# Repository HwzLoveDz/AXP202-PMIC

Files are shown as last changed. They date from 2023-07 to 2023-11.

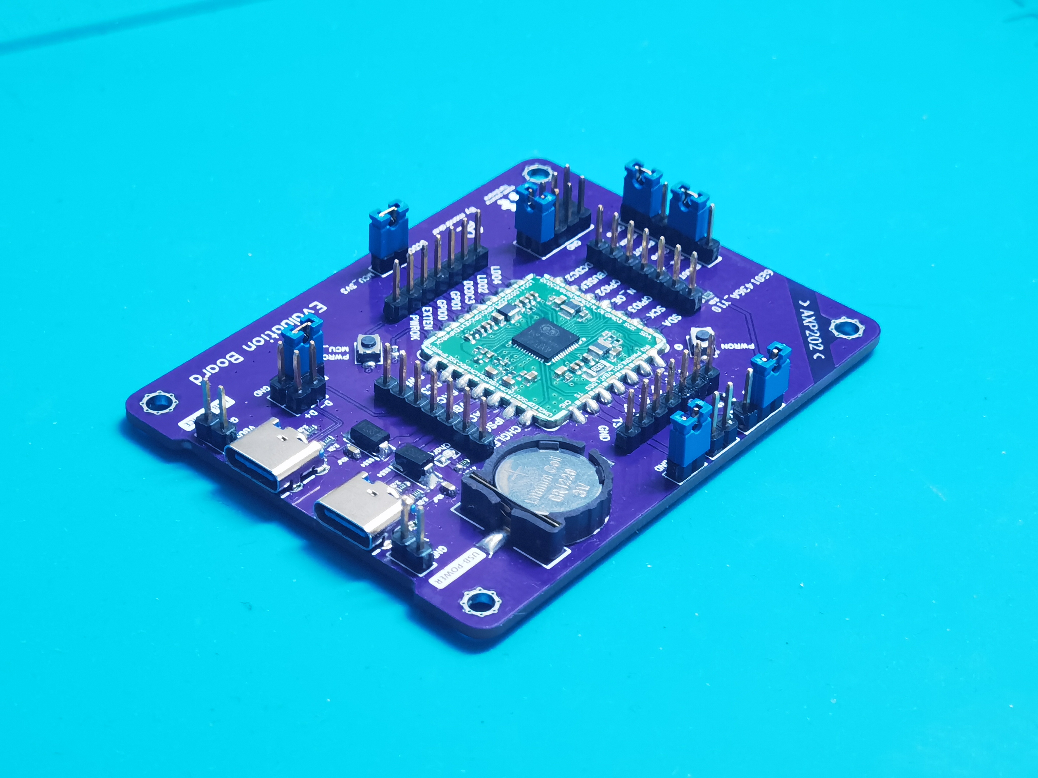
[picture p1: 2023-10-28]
hardware/底板图片.jpg

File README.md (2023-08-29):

# AXP202-PMIC
AXP202 Power management IC（AXP202电源管理芯片）

 
  
| 文件名称(file name) | 描述(description) |
|---|:---:|
| README_CN.md | [中文文档(Chinese Document)](https://github.com/HwzLoveDz/AXP202-PMIC/blob/main/README_CN.md) |
| README.md | [英文文档(English Document)](https://github.com/HwzLoveDz/AXP202-PMIC/blob/main/README.md) |

**Note:** The document is machine translated and does not guarantee that all sentences will be smooth or error-free

***

The hardware part is open source in the Lichuang open source platform, link address: https://oshwhub.com/mondraker
Sometimes if it is not reviewed on Saturdays and Sundays, the project will disappear and you can see the backup on Github and Gitee

##### If there is a problem, directly into the Q group to bombard me: 735791683🧨
* Why not use the latest version of AXP2101? First of all, the AXP2101 has too many functions, and the current DIY small devices simply cannot use so much. Secondly, because the price of the main product is relatively expensive, it is 10 times that of AXP202 (but if you have friends who need to do it later, you can also make one)
* The project has been verified for a long time, providing packaging, 3D files, etc., **sufficient information (including ESP-IDF routines and Arduino routines, Chinese and English manuals)**, and this stamp hole is also **no extra charge** at no extra charge, do not choose the half-hole process to grind 🤣 it yourself
* One chip 1.8 yuan, the rest are resistance, capacitance and inductance, a piece of "own whole" **within three dollars**
* Related materials, [BOM form](https://easyeda.online/ibom/d5313712.html), and component-related links are attached at the end of the article
* After a while, I will come out with a whole batch of modules of gold immersion + half-hole process, and put them in the TB shop together with snowflake lights: [Ultraman's electronic planet](https://m.tb.cn/h.50LlvTB )
* This module **P2P is compatible with AXP209** power management chip, and the program is also compatible, but AXP209 has one more OTP decoder than AXP202, and the register can be operated in the code

* * *

# Preface (Small Talk)
* Hello, everyone hasn't seen you for a long time, I haven't sent anything new for most of the year, and my friends think I'm retiring. In fact, I have been practicing in retreat during this time, busy with graduation projects, and learning ESP-IDF and LVGL by the way.
* The article may be relatively long, but this module is really easy to use, the information is very complete, I really hope that every interested friend can master him.
* Of course, I will share my gains during this period with you after sorting out the information later. Since the development board to be open source in two days also uses this power module, this module is first open sourced. (as shown below)

###### [Open source video trailer, click me directly](https://b23.tv/cWTMeIv)

**Development Board**
* 

**Module**
* 

**Test Baseplate**
* 

**Commented schematics**
* 
# Body (AXP202 Power Management Chip)
## Notes
### Since the chip has so many functions, I will divide it into the following parts for a general introduction
1. **Function part**: This part mainly introduces the design purpose, design ideas, chip functions, chip parameters and application scenarios

2. **Hardware part**: This part mainly introduces the chip peripheral circuit (detailing the functions and selection of each special device), module peripheral circuit (this part involves the default power supply voltage setting and boot mode setting), power module test backboard explanation, PCB parameters and precautions (thickness, etc.), power module wiring in the circuit (due to the particularity of the power module, it is easy to be unable to communicate)

3. **Software Part**: This part mainly introduces the functions implemented by the software, the use of routines, precautions, etc

4. **Video and related links section**: This part mainly includes the address of AXP173 project, the Github address of AXP202 project, the use of online bom and welding point tools (a very powerful thing developed by friends) and the video display and explanation of AXP202 module (strong response to launch a hand, now temporarily pigeon)

## Features section
### Design purpose
**1. When designing hardware, the power supply part has always been the beginning and top priority. I find that the core issues that are often discussed in everyone's daily production are:**
* How to design the power supply
* Find a small LDO
* Find an efficient DCDC
* Ask for a battery charging chip
* Where to find cheap power chips

**2. There are also many problems that players often encounter :**
* How to achieve efficient and reliable power path management of external input power supply and battery
* How to achieve long press to turn on and off
* How to accurately detect the battery level
* How to get the real-time status of the power supply
* What to do with low power consumption, what to do, what to do

**Well, I'll tell you now that there is a chip that can implement all the above functions, and is small in size, high efficiency, low in power consumption, and attractive in price???**



### Chip function
**1. on the function. (Official documentation is below)**
* 

**2. on the overview. (Official documentation is below)**
* 

### Chip parameters
**Here are mainly examples of power output capability parameters, other power parameters go to the data sheet. (Official documentation is below)**
* 

**If you also need 5V output, then the use of module IPSOUT pin + DCDC5V buck circuit can be easily achieved, the output capability depends on the input capability of the external power supply, and the chip has an EXTEN pin to control the EN pin of the external DCDC chip, saving the functional pin of the NCU, too fragrant. (Official documentation is below)**
* 

### Design ideas
**It is convenient to use the stamp hole module type directly, because the resistance and capacitance parameters on the periphery of this chip are relatively strange.**
* In order to facilitate the design and soldering of PCB circuit boards and increase the success rate, this design adopts modular thinking, the AXP202 peripheral circuit is packaged as a stamp hole module soldered to the motherboard, and all the user-defined pins are led out, so that it is convenient to use the resistance of the corresponding resistance value on the motherboard to configure these pins.

* In order to unify the package, the design uses a standard 2.54mm pitch LCC stamp hole for easy soldering, and a 4-layer PCB design is used to reduce the package size and bring out all the necessary functions.
### Application scenario
**All devices containing a microcontroller. (Official documentation is below)**
* 

## Hardware section
### Chip peripheral circuitry
**The schematic is written in detail, here is a brief summary**

* First of all, the power input part, **as shown in the upper left area of the figure**. VBAT is the positive terminal of the battery, and a 0603 package is connected in parallel with a 10uF withstand 16V capacitor for filtering. ACIN is an external DC power supply pin, which can accommodate 5V/2A power supply entry, VBUS is an external USB power input, which can accommodate 5V/1A power supply entry, so a 0603 package 4.7uF capacitor is connected in parallel for power supply filtering, and two 2.2ohm resistors are deliberately connected in series to prevent oscillation, reduce the capacitor charging speed, and better absorb the noise of the power supply. This section can also be paralleled with Zener diodes at the power supply to reduce the risk of high-voltage breakdown, which is not added due to the size limitation of the module and the fact that it is not functionally sensitive. BACKUP is the positive terminal of the external backup battery, connected to a conventional RTC/BIOS battery.

* This is followed by the DCDC buck section, **as shown in the upper right area of the figure**. This part of the circuit is an independent area that requires external access to the system input power supply IPSOUT, which can reduce the internal voltage IPSOUT to the power chip voltage regulation range, if the application does not need to use a DC-DC only need to suspend the corresponding LX pin. 4.7uH inductance is recommended when the output voltage is below 2.5V, 2.2uH inductance is recommended when the output voltage is above 2.5V, and the inductor saturation current needs to be greater than 50% of the maximum required current, here because 4.7uH has 0806 package, so all 4.7uH is used, also to reduce the volume. R17 must be 30mΩ/1%/1206 resistance, PCB layout attention chip 42/43 pin must be connected to R17 resistance PAD to ensure that the signal is detected directly from the resistor PAD, because R17 for the battery charging current, discharge current and charging voltage of the detection resistance, not only high accuracy but also need to strictly consider interference in the layout.

* This is followed by the exit of the signal and function pins, as well as the circuit section outside the internal reference voltage of the chip, **as shown in the lower left area of the figure**. The following two GPIOs have additional functions in addition to the normal input and output capability: GPIO0: ADC/LDO5 (output drive capability of 50mA), GPIO1: ADC. PWRON is the power chip boot pin, active low, R24 pull-up to LDO1 to prevent false triggering. N_OE can be used to power on the device directly via an external power supply. N_VBUSEN to choose whether VBUS power is enabled. IRQ interrupt signal pin with optional pull-up to LDO1 or MCU_3V3. I2C uses a 2.2k resistor to pull up to MCU_3V3.

* Finally, there is the LDO (Low Dropout Linear Regulator) output section, **see the lower right area of the figure**. This part is also a separate area in the functional block diagram, which requires an external access system to supply ISPOUT. PWROK is the MCU enable pin, and the RESET button is connected to the EN pin of the MCU to restart the MCU and pull up to the MCU power supply pin. DC3SET sets the pin for DCDC3 voltage, 3.3V/2.5V for APS or LDO1, 1.8V for ground, and 1.2V/1.5V for floating.

* 

### Module peripheral circuit
**The picture below is very detailed, not to be repeated**

* 

### Power module test backplane explanation
**As shown in the figure above, all functions are introduced, some pins that can be set externally on the chip can be set using a jump cap, and a 5V DCDC boost is added for basic testing, and the ground wire leads less and can be added at your discretion. Or draw a test board according to the main control chip to be used, my test base board is only used to screen which chip is suitable and basic functional testing, because I directly drew the ESP32 test board, so I did not continue to optimize this base board (there may be a breadboard module later).**

### Wiring of the power module in the circuit
**Compared with ordinary I2C modules, the power management module also provides power to the main control chip, in addition, AXP202 must be in the boot state, must be common, otherwise the two can not communicate normally.**
* 

### PCB parameters and stamp hole handling considerations
**Place a single 1mm (the picture below is 1.6mm very thick, just for demonstration purposes), four layers. There is no need for the half-hole process, after coming back, it is crimped, and you need to use tweezers to cut out the excess copper in the half-hole, and then grind it off with sandpaper of about 800 mesh. (The following is a simple step-by-step demonstration)**

* Before processing (silver for OK, yellow for OK)
* 
* Processing (tweezers pick out)
* 
* Processing (after picking out)
* 
* 
* In process (sanding)
* There is no picture, don't try too hard, grind and take a look, don't grind the copper on the edge of the board.
* After treatment (you can use higher mesh sandpaper to polish it finely)
* 

### PS
**The hole on the top of the module is for easy disassembly and assembly**
* 

## Software section
### **[GitHub link](https://github.com/HwzLoveDz/AXP202-PMIC)**
### **[Gitee link](https://gitee.com/mondraker/AXP202-PMIC)**
### Statement:
* axp20x libraries and Arduino-related routines are all from Lewis He, thanks to the open source (open source license: MIT)
* Original GitHub link: github:https://github.com/lewisxhe/AXP202X_Libraries
* Subsequent routines will be written around this library, adding other commonly used registers and functions, such as LED indicator charging control, etc., and future changes will be updated to GitHub/Gitee

### Description:
* The library is also compatible with AXP173/192/202, etc
* Basically realize all the functions of the chip
* There are relevant function comments in the code, which can be studied and written with the official register document
* The code is written using an independent I2C interface, and only need to write an interface library to port to other platforms, which is very convenient
* **If you have doubts in the code, you can refer to this open source [AXP173](https://oshwhub.com/mondraker/axp173) to learn, or bombard me in the crowd**

## Video and related links section
* **[GitHub profile](https://github.com/HwzLoveDz)**
* **[Gitee profile](https://gitee.com/mondraker)**
* **[bilibili homepage](https://space.bilibili.com/240319986)** **(here is the AXP202 (QFN) chip soldering tutorial)**
* **[Online BOM address](https://easyeda.online/ibom/d5313712.html)** **(developed by a friend, like ibom, but online, and mobile phone can also be browsed, a later issue will focus on him)**
* **QQ Group Number: 735791683**
* **Device purchase link in accessory BOM**

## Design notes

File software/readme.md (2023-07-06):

以下代码中AXP20X的所有库均来自Lewis He大佬，该库同时兼容AXP173/192/202等，原GitHub链接：
github:https://github.com/lewisxhe/AXP202X_Libraries

Arduino文件夹下AXP202X为标准arduino库，可以移到libraries文件夹下直接使用；
ESP-IDF文件夹为ESP-IDF例程，我使用idf5.0版本编译成功；

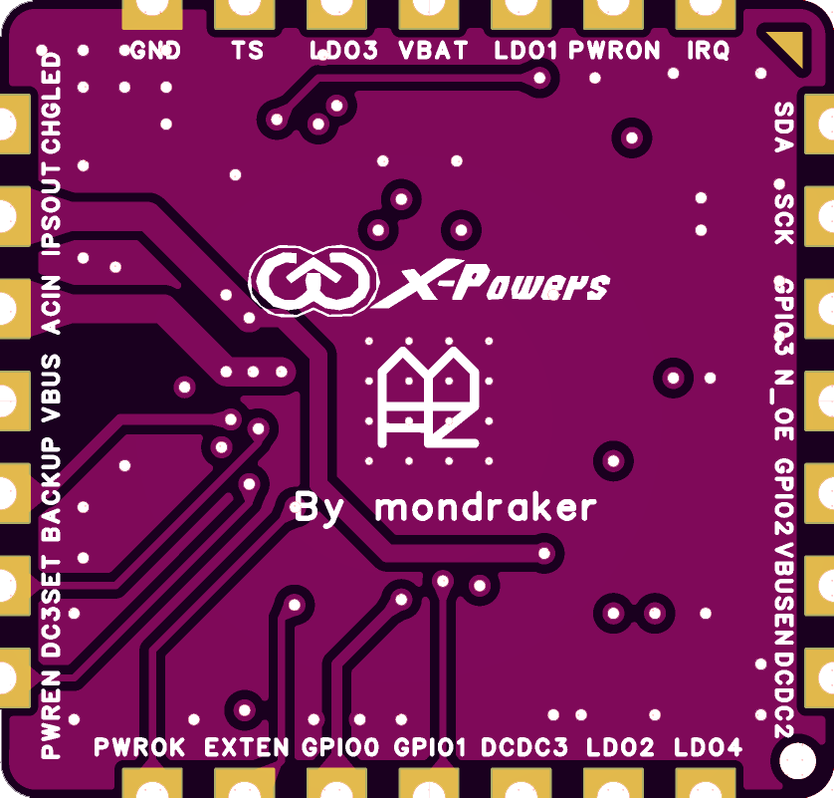
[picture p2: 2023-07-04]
hardware/AXP202模块渲染/F1.png

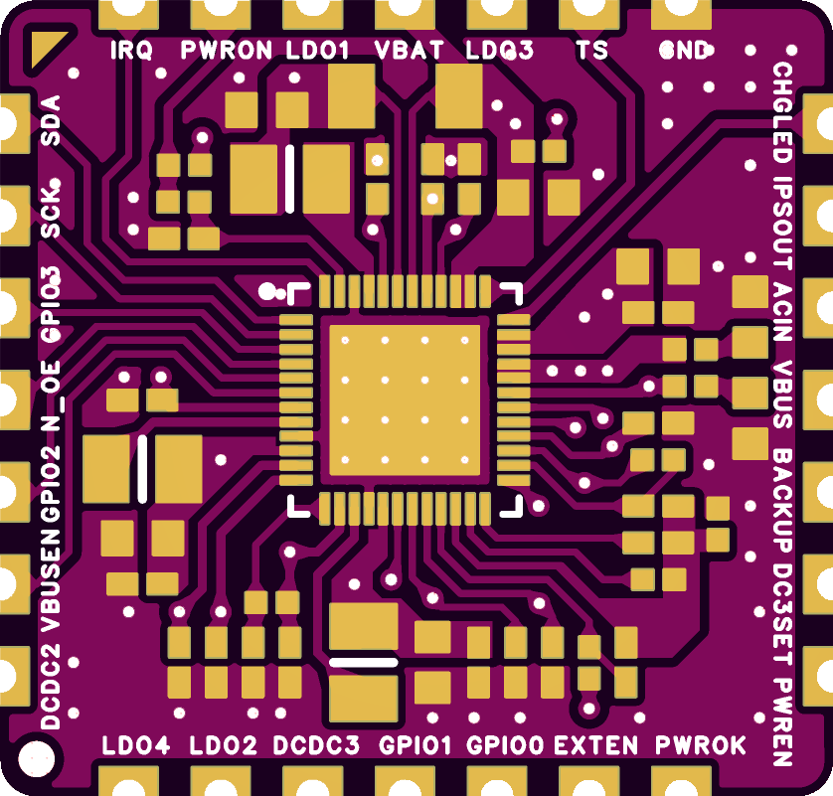
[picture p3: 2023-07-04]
hardware/AXP202模块渲染/z11.png

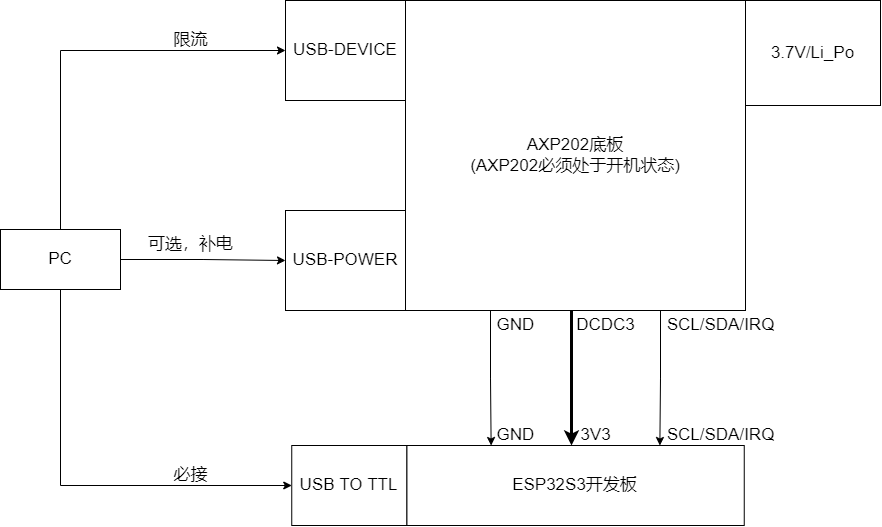
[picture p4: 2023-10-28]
hardware/底板与开发板接线框图.drawio.png

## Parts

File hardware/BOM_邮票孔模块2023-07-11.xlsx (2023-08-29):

在线BOM与焊接点位地址（手机也可查看）：https://easyeda.online/ibom/d5313712.html
ID | Name | Designator | Footprint | Quantity | Manufacturer Part | 立创料号 | 备注
1 | AXP202 | U1 | QFN48 | 1 | 【淘宝】https://m.tb.cn/h.5agVBVR?tk=pbYndH4zCvU CZ0001 「全新原装正品 AXP202 贴片QFN 电源管理芯片」 点击链接直接打开 或者 淘宝搜索直接打开 |  | 链接挂了就直接TB搜索AXP202，其中我只测试过鹏盛微、义胜、品信达三家，其中义胜、品信达两家芯片丝印一致。三家都可以用，都没有什么问题，鹏盛微家的没有打磨痕迹。
电容
2 | 10uF/0603 | C1,C11,C12,C14,C18 | C0603 | 5 | 随便品牌都行，耐压6.3V以上
3 | 1nF | C2,C17 | C0402 | 2
4 | 2.2uF | C3 | C0402 | 1
5 | 10uF | C4,C9,C19 | C0402 | 3
6 | 1uF | C5,C7,C20,C23,C10 | C0402 | 5
7 | 4.7uF | C6,C8,C24,C25,C26 | C0402 | 5
8
9 | 220nF | C13,C22 | C0402 | 2
10 | 4.7uF/0603 | C15,C16 | C0603 | 2
11 | 100pF | C21 | C0402 | 1
电阻
12 | 10k | R2 | R0402 | 1 | 随便品牌都行，但是 精度必须至少±１%
13 | 2.2R | R4,R6 | R0402 | 2
14 | 1R | R5 | R0402 | 1
15 | 200k/1% | R8 | R0402 | 1
16 | 1k | R10 | R0402 | 1
17 | 0R | R11,R12 | R0402 | 2
18 | 4.7k | R24 | R0402 | 1
19 | 0.03Ω | R17 | R1206 | 1 | RTT06R030FTP | C104923 | 只要精度高，什么牌子无所谓，我用的这个
电感
20 | 4.7uH | L1,L2,L3 | L0806 | 3 | MPL2016S4R7MHT | C98335 | 追求功耗推荐用这个，额定1.1A，但内阻110mΩ
 |  | L1,L2,L3 | L1008 | 3 | FHD252012S-4R7MT | C602016 | 追求性能推荐用这个，额定1.6A，但内阻260mΩ
电感替代型号

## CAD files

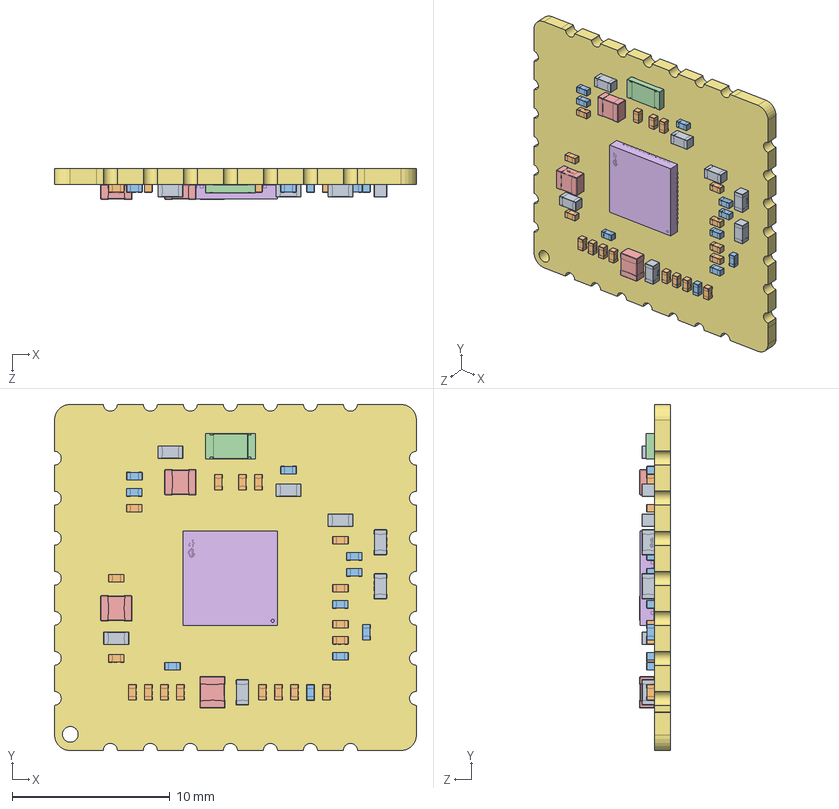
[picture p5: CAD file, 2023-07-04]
hardware/AXP202模块渲染/3D_邮票孔模块_2023-03-31.step.SLDASM
23.0 x 22.0 x 1.95 mm
SOLID.step x 7
SOLID-0.step x 18
SOLID-1.step x 10
COMPOUND.step
SOLID-2.step x 3
COMPOUND-3.step
COMPOUND-4.step

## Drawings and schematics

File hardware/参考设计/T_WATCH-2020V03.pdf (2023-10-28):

USB | UART

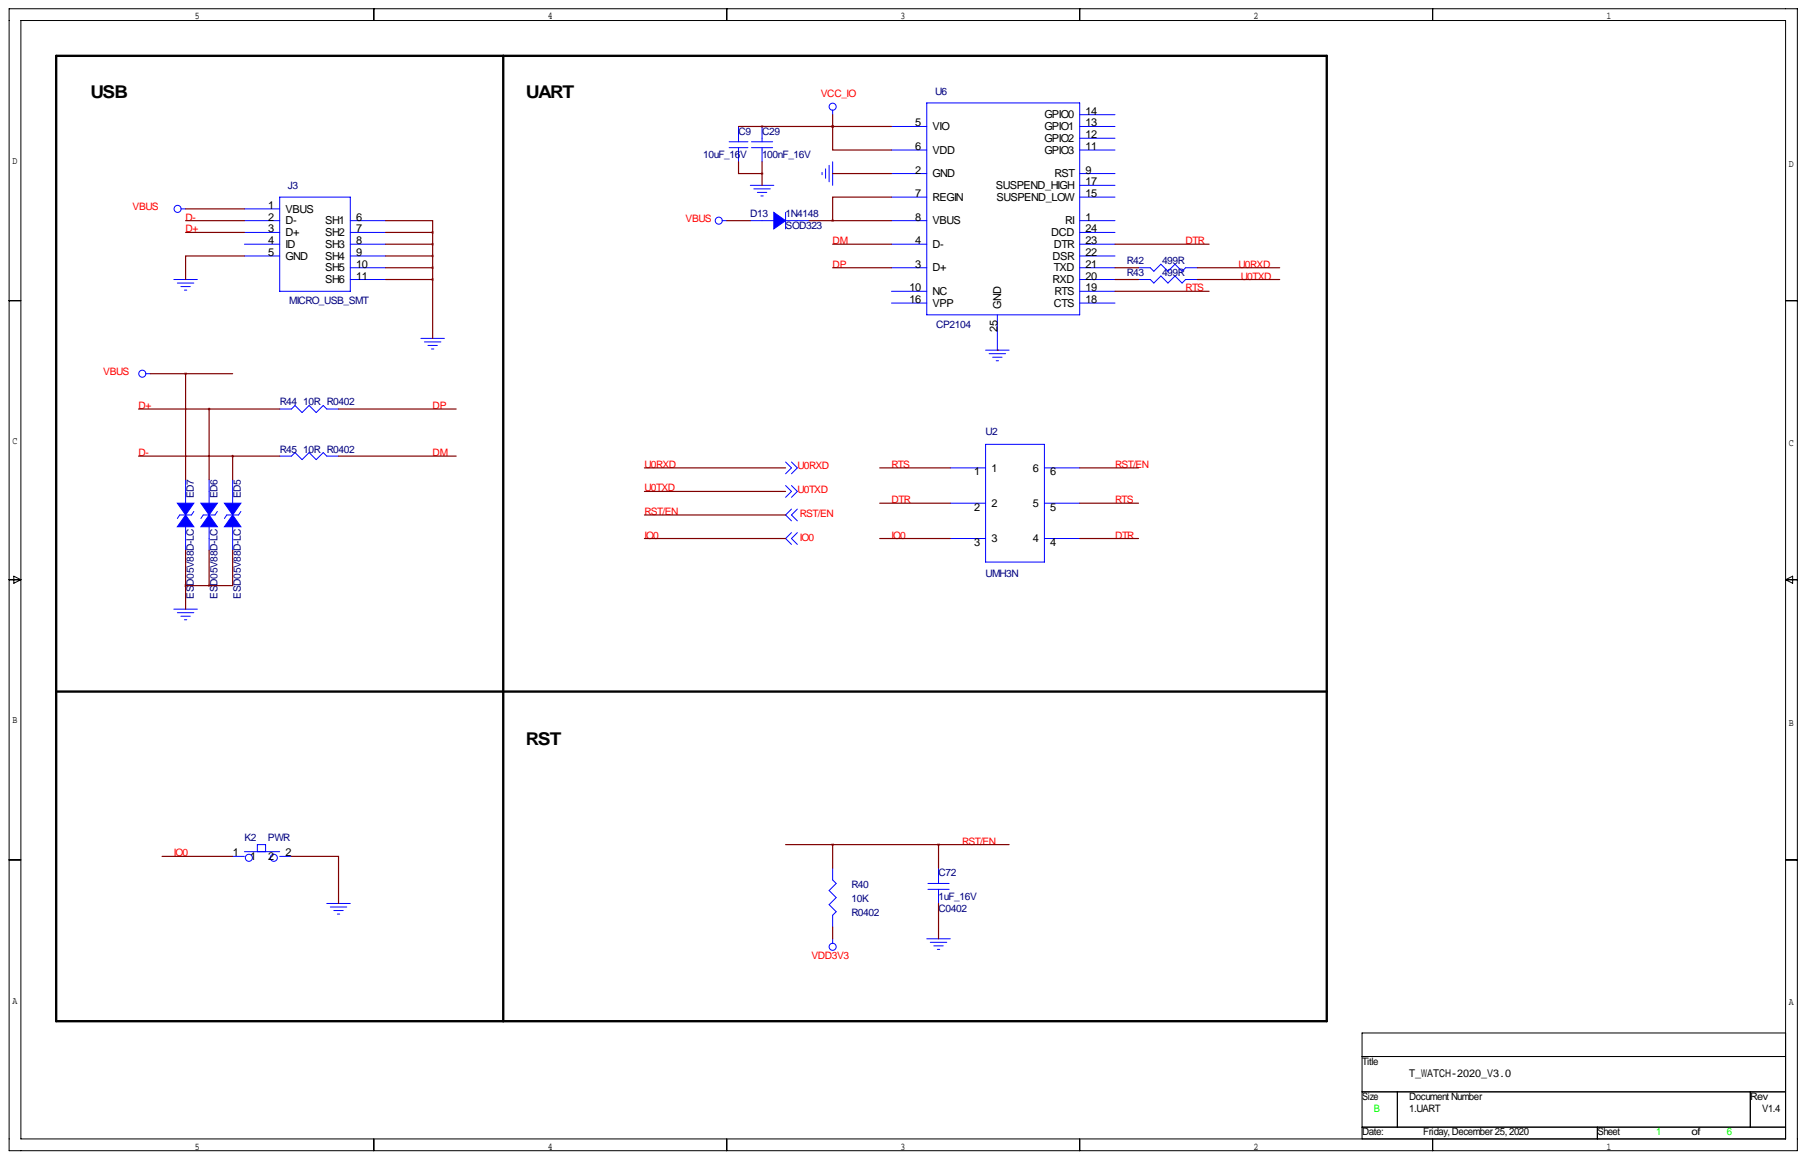
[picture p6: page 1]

Size B | Document Number 1.UART | Rev V1.4

Date: Friday, December 25, 2020 | Sheet of

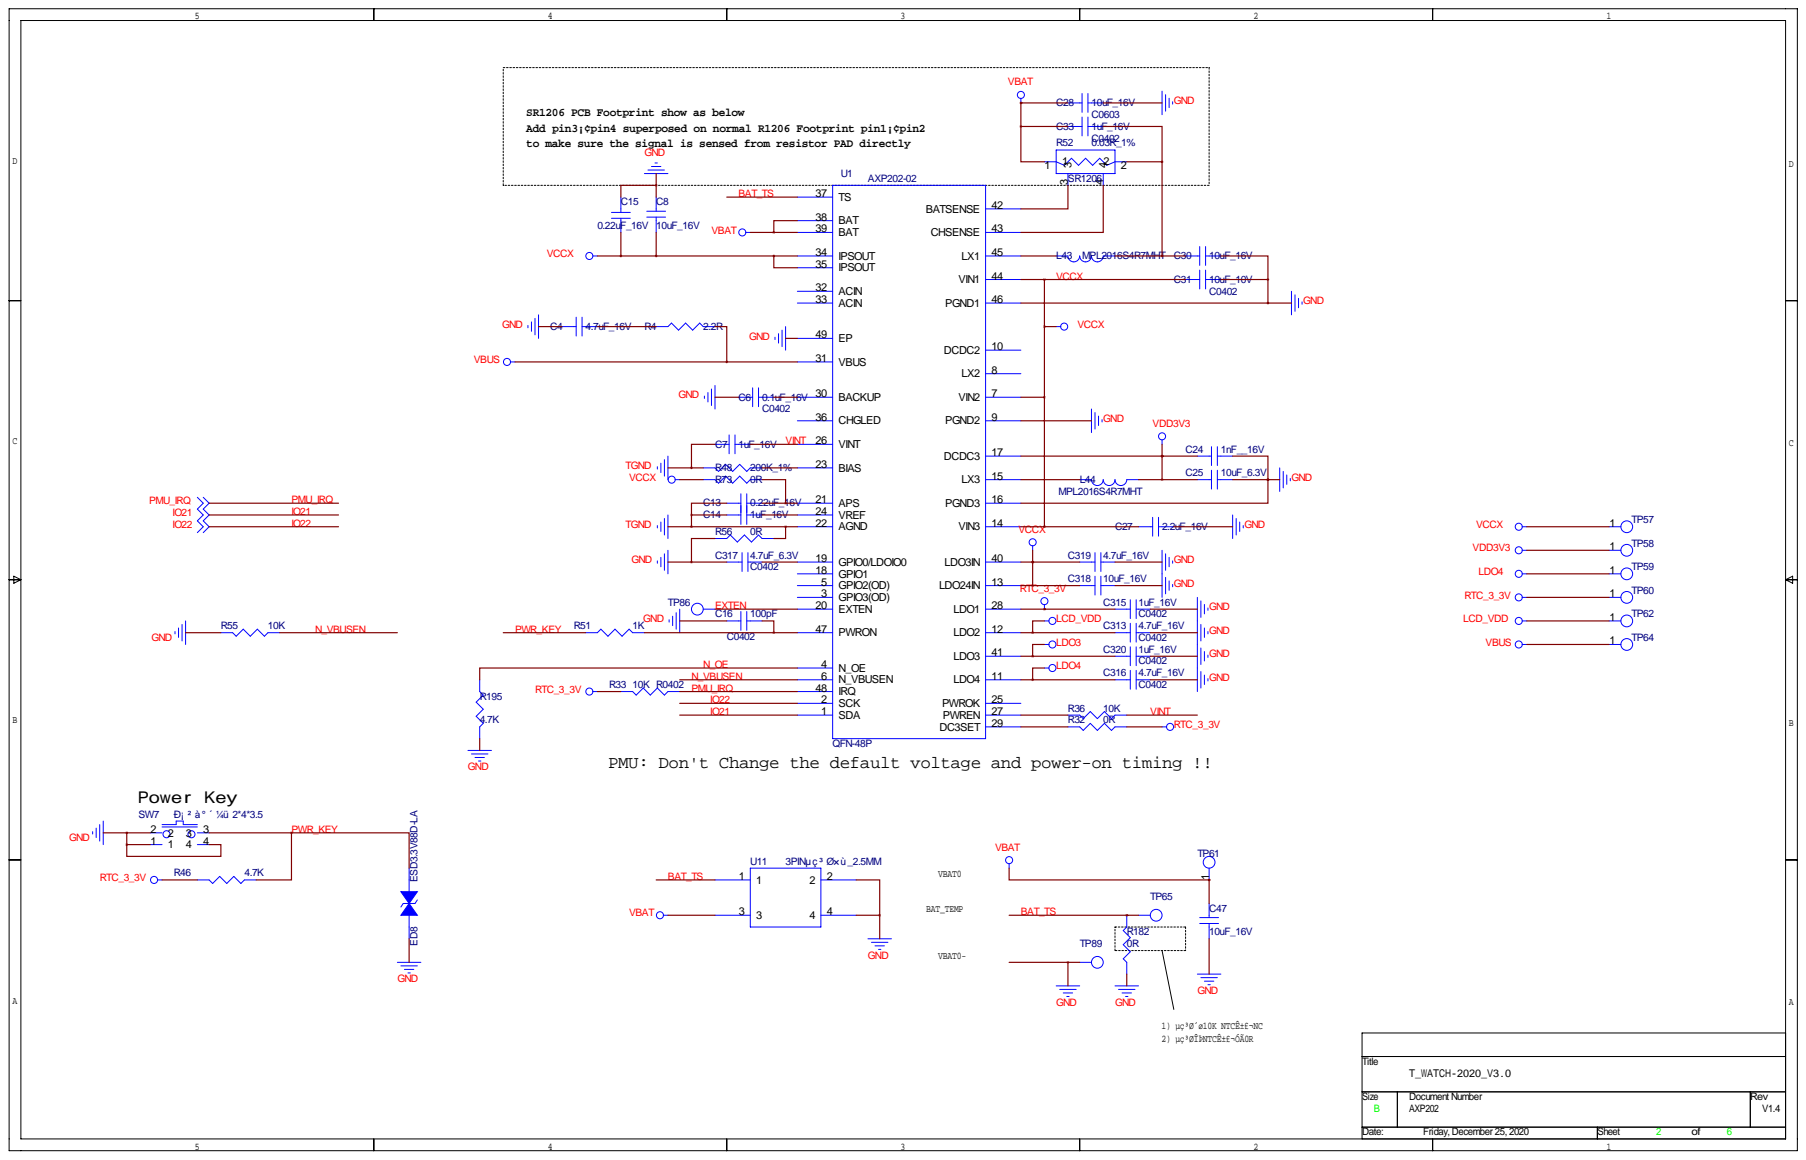
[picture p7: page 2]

SR1206 PCB Footprint show as below

Add pin3¡¢pin4 superposed on normal R1206 Footprint pin1¡¢pin2

to make sure the signal is sensed from resistor PAD directly

15 LX3 | MPL2016S4R7MHT

C14 | 1uF_16V | 14 VIN3

40 LDO3IN

PMU: Don't Change the default voltage and power-on timing !!

## ESP32 Module:with 1.8V Flash & SRAM

The operating voltage for signals marked in blue is 1.8V.

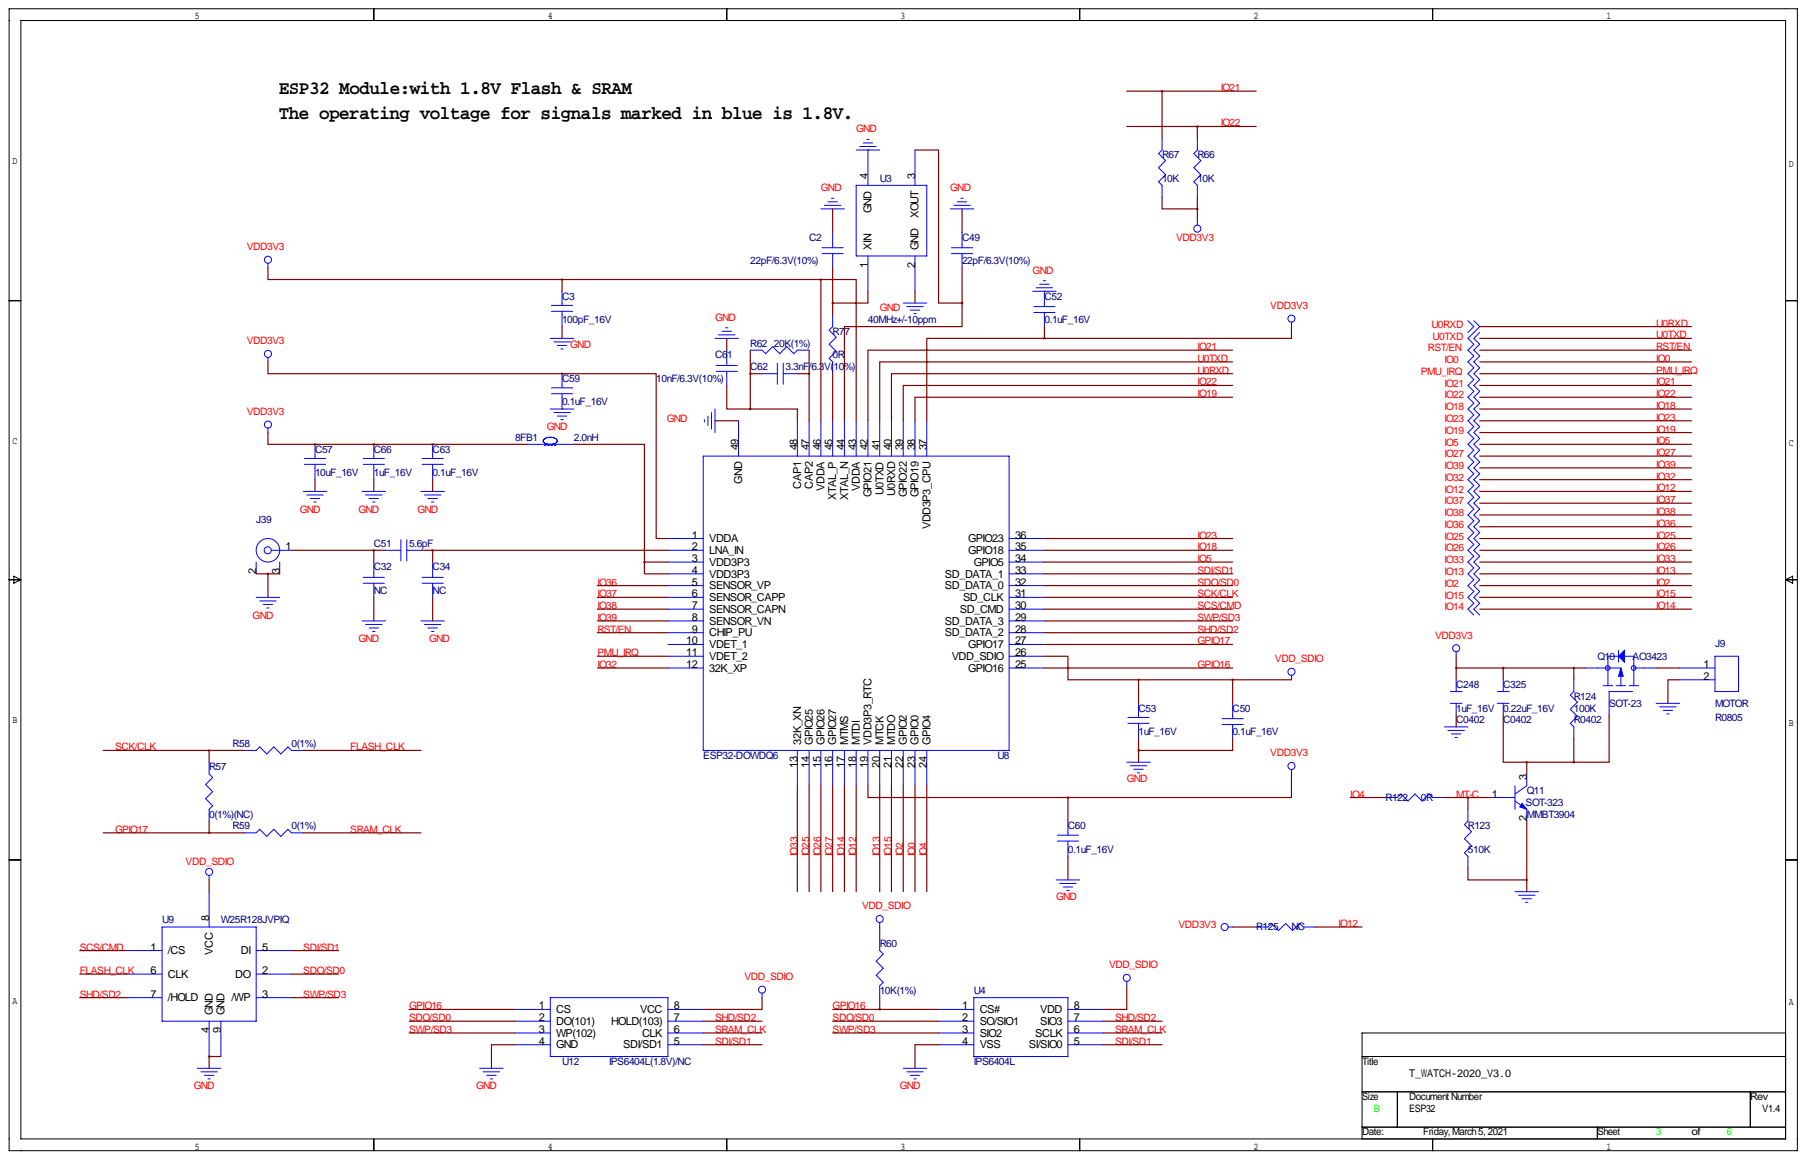
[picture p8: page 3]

Size B | Document Number ESP32 | Rev V1.4

Friday, March 5, 2021

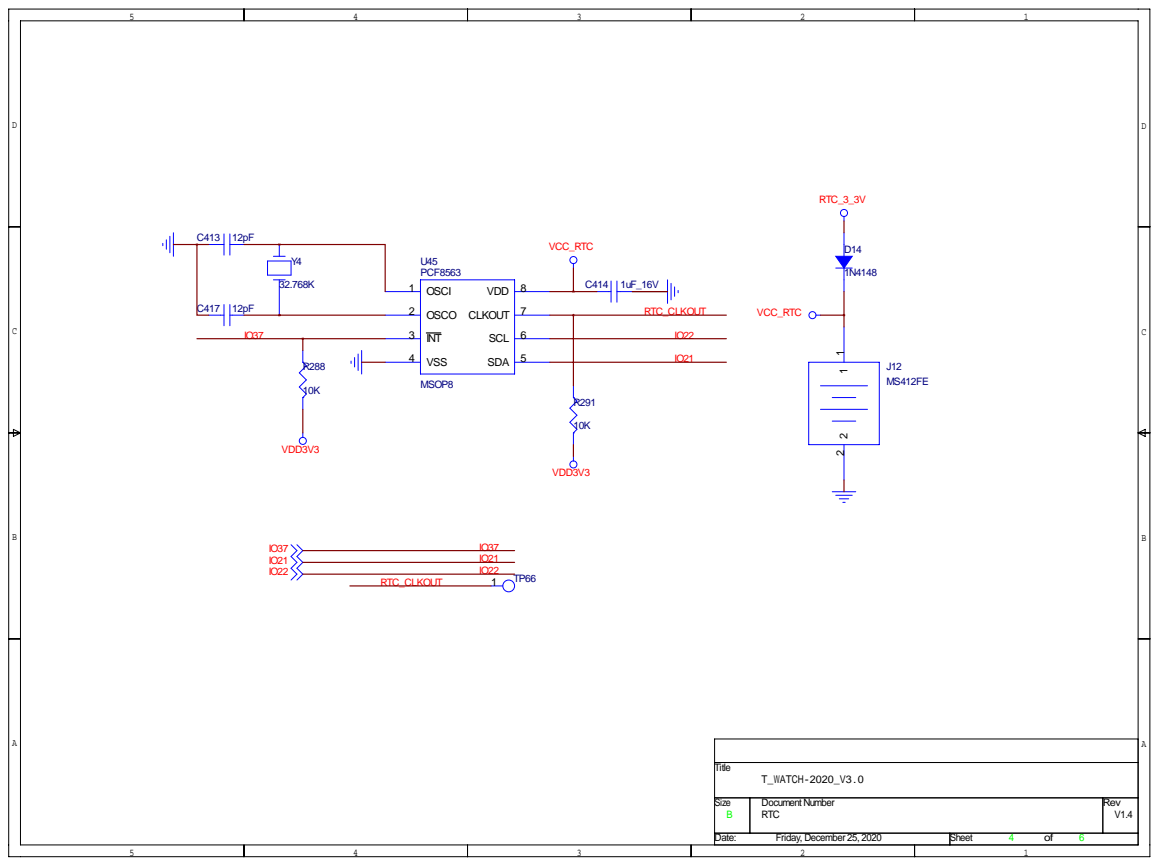
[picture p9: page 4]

# LCD_1.54-TOUCH

# IF=3*15MA

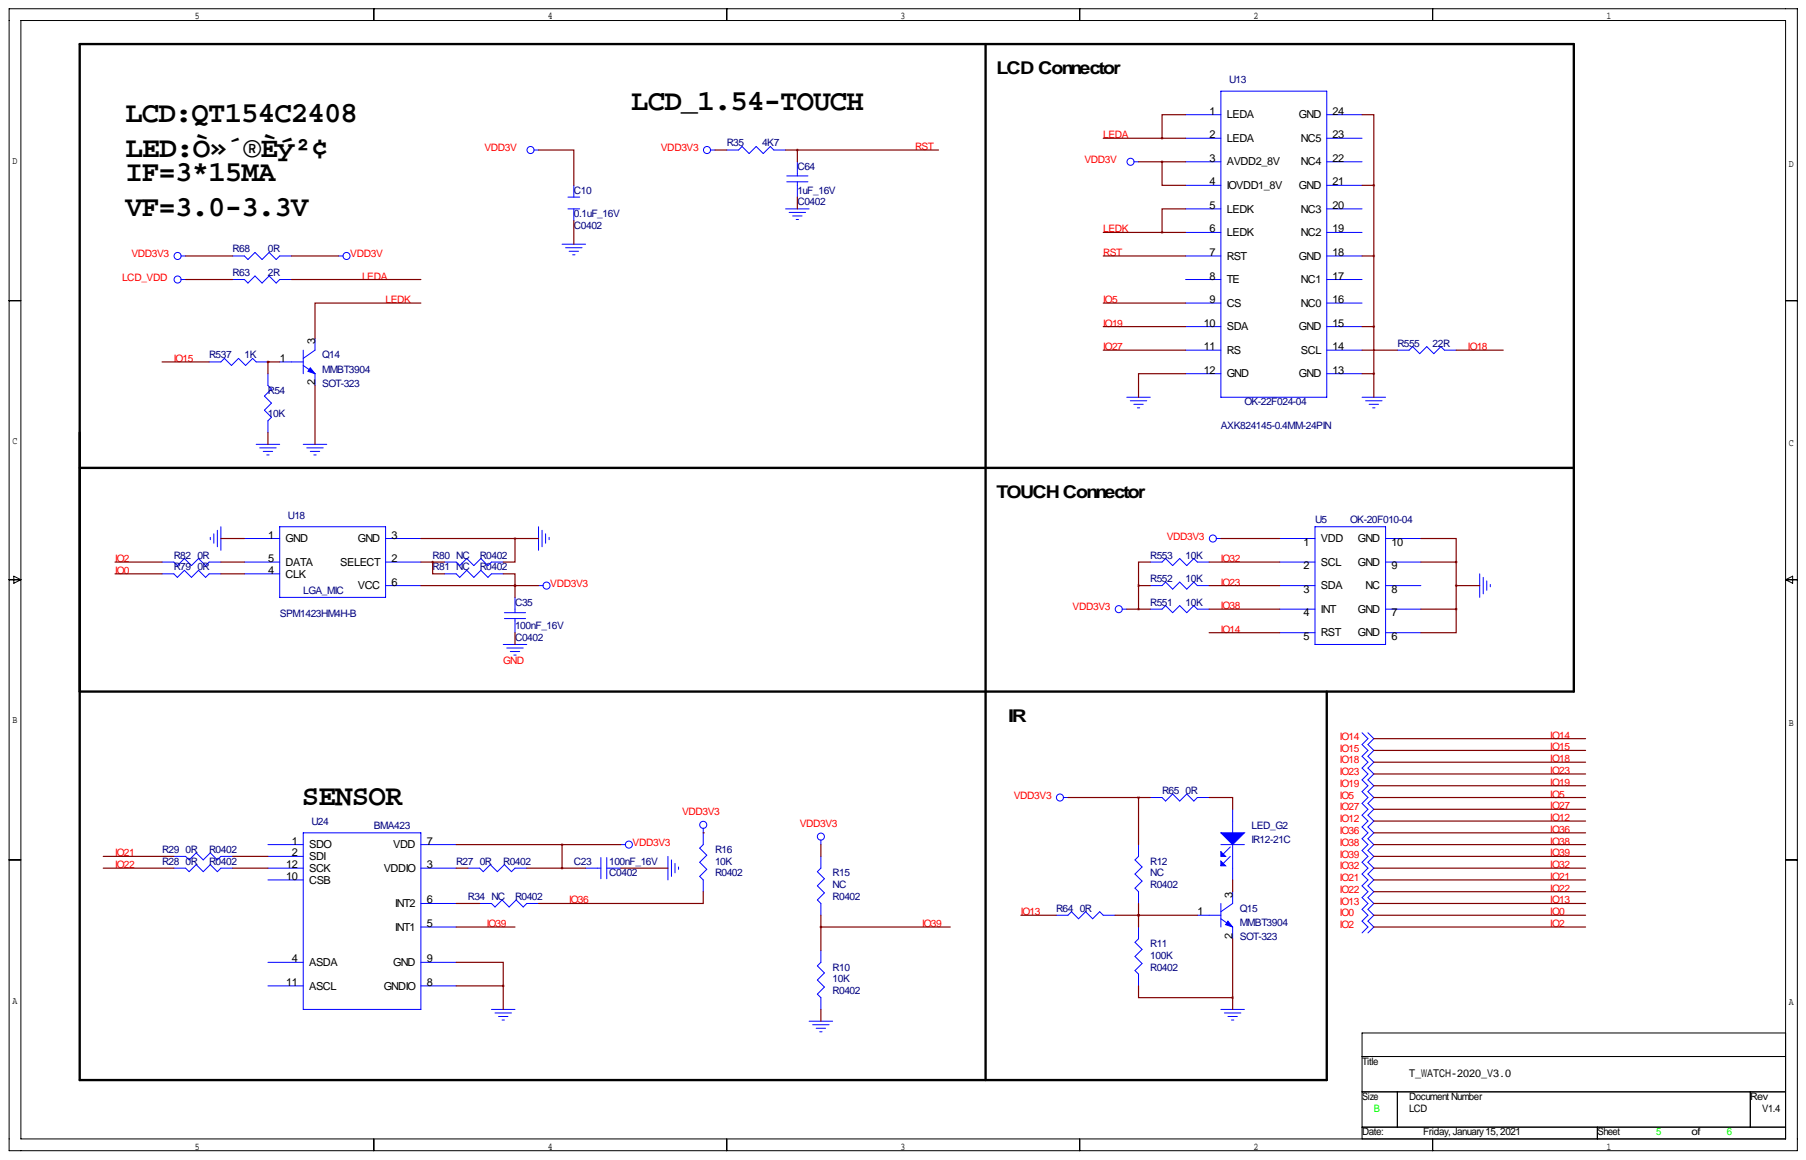
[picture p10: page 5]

Size B | Document Number LCD | Rev V1.4

Friday, January 15, 2021

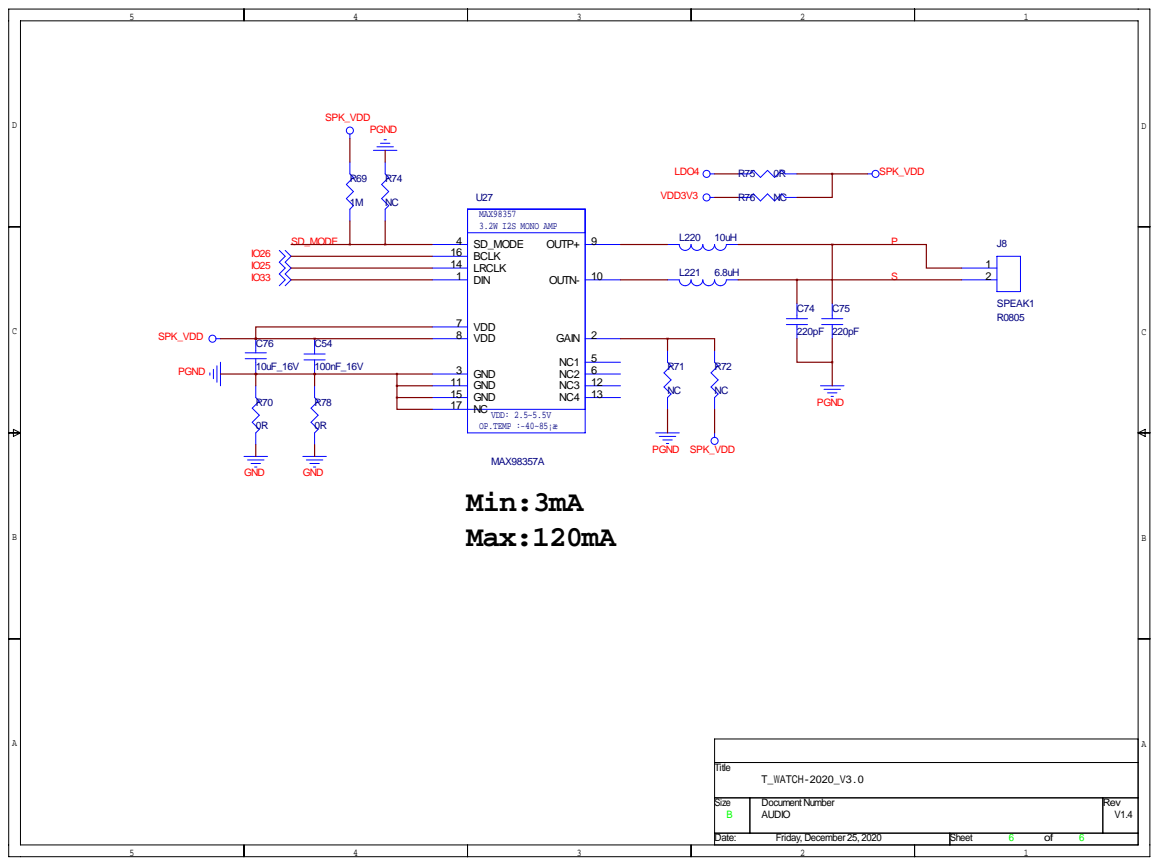
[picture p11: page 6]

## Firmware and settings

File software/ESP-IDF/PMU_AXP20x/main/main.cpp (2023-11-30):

/////////////////////////////////////////////////////////////////
/*
MIT License

Copyright (c) 2020 lewis he

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
main.cpp - AXP202X_Library idf Programming example
Created by Lewis he on July 29, 2020.
github:https://github.com/lewisxhe/ESP_IDF_AXP20x_Library
*/
/////////////////////////////////////////////////////////////////
//! 请注意外设最大支持电压，调压可能会损坏外设器件
//IIC部分官方文档：https://docs.espressif.com/projects/esp-idf/en/release-v4.4/esp32c3/api-reference/peripherals/i2c.html

extern "C" {

#include "i2c_port.h"

}

#include "axp20x.hpp"

static const char *TAG = "AXP20x";

// //! ESP32C3只有I2C_NUM_0一个I2C通道

static QueueHandle_t gpio_evt_queue = NULL;

static void IRAM_ATTR axp_isr_handler(void *arg)
{
    uint32_t gpio_num = (uint32_t) arg;
    xQueueSendFromISR(gpio_evt_queue, &gpio_num, NULL);
}

static void axp_irq_init()
{
    static gpio_config_t io_conf;
    //enable interrupt
    io_conf.intr_type = GPIO_INTR_NEGEDGE;
    //set as input mode
    io_conf.mode = GPIO_MODE_INPUT;
    //bit mask of the pins that you want to set
    io_conf.pin_bit_mask = GPIO_INPUT_PIN_SEL;
    //disable pull-down mode
    io_conf.pull_down_en = GPIO_PULLDOWN_DISABLE;
    //enable pull-up mode
    io_conf.pull_up_en = GPIO_PULLUP_ENABLE;
    //configure GPIO with the given settings
    gpio_config(&io_conf);
    //change gpio intrrupt type for one pin
    gpio_set_intr_type(AXP_ISR_GPIO, GPIO_INTR_NEGEDGE);
    //install gpio isr service
    gpio_install_isr_service(0);
    //hook isr handler for specific gpio pin
    gpio_isr_handler_add(AXP_ISR_GPIO, axp_isr_handler, (void *) AXP_ISR_GPIO);
    //create a queue to handle gpio event from isr
    gpio_evt_queue = xQueueCreate(10, sizeof(uint32_t));
}

static void axp_init()
{
    if (axp.begin(twi_read, twi_write, AXP202_SLAVE_ADDRESS))
    {
        ESP_LOGE(TAG, "Error init axp20x !!!");
        while (1);
    }
    ESP_LOGI(TAG, "Success init axp20x !!!");
}

static void axp_config()
{
    // 两个警告等级（类似于手机20%一提醒，10%一提醒）和一个关机电压（类似于手机3%关机，实际显示0%）
    axp.setVWarningLevel1(3450);
    axp.setVWarningLevel2(3400);
    axp.setPowerDownVoltage(2600);
    uint16_t level1 = axp.getVWarningLevel1();
    uint16_t level2 = axp.getVWarningLevel2();
    uint16_t level3 = axp.getPowerDownVoltage();
    ESP_LOGI(TAG, "getVWarningLevel1:%u mV", level1 );
    ESP_LOGI(TAG, "getVWarningLevel2:%u mV", level2);
    ESP_LOGI(TAG, "getPowerDonwLevel3:%u mV", level3);

    axp.setPowerOutPut(AXP202_DCDC3, AXP202_ON); // 主控供电，十轴传感器供电
    axp.setPowerOutPut(AXP202_DCDC2, AXP202_ON);

    axp.setLDO2Voltage(3300); // 屏幕与SD卡供电
    axp.setPowerOutPut(AXP202_LDO2, AXP202_ON);

    axp.setLDO4Voltage(AXP202_LDO4_3300MV); // 音频供电
    axp.setPowerOutPut(AXP202_LDO4, AXP202_ON);

    axp.setLDO3Voltage(3500); // 触觉驱动器供电
    axp.setPowerOutPut(AXP202_LDO3, AXP202_ON);

    axp.setPowerOutPut(AXP202_EXTEN, AXP202_ON);

    if (axp.isDCDC2Enable())
    {
        ESP_LOGI(TAG, "DC2: %u mV", axp.getDCDC2Voltage());
    }
    else
    {
        ESP_LOGI(TAG, "DC2: DISABLE");
    }

    if (axp.isDCDC3Enable())
    {
        ESP_LOGI(TAG, "DC3: %u mV", axp.getDCDC3Voltage());
    }
    else
    {
        ESP_LOGI(TAG, "DC3: DISABLE");
    }

    if (axp.isLDO2Enable())
    {
        ESP_LOGI(TAG, "LDO2: %u mV", axp.getLDO2Voltage());
    }
    else
    {
        ESP_LOGI(TAG, "LDO2: DISABLE");
    }

    if (axp.isLDO3Enable())
    {
        ESP_LOGI(TAG, "LDO3: %u mV", axp.getLDO3Voltage());
    }
    else
    {
        ESP_LOGI(TAG, "LDO3: DISABLE");
    }

    if (axp.isLDO4Enable())
    {
        ESP_LOGI(TAG, "LDO4: %u mV", axp.getLDO4Voltage());
    }
    else
    {
        ESP_LOGI(TAG, "LDO4: DISABLE");
    }

    if (axp.isExtenEnable())
    {
        ESP_LOGI(TAG, "Exten: ENABLE");
    }
    else
    {
        ESP_LOGI(TAG, "Exten: DISABLE");
    }

    // When the chip is axp192 / 173, the allowed values are 0 ~ 15,
    // corresponding to the axp1xx_charge_current_t enumeration
    //  axp.setChargeControlCur(AXP1XX_CHARGE_CUR_550MA);

    // axp202 allows maximum charging current of 1800mA, minimum 300mA
    axp.setChargeControlCur(300);

    axp.setChgLEDContrl(AXP20X_LED_CHARGING_CTL);   // CHGLED由充电状态控制
    axp.setChgLEDChargingMode(AXP20X_LED_LIGHT_WHEN_CHARGING);  // CHGLED由充电状态控制模式
    // axp.setChgLEDContrl(AXP20X_LED_REG_32H_CTL); // CHGLED由REG32H控制
    // axp.setChgLEDMode(AXP20X_LED_BLINK_4HZ);  // CHGLED由REG32H控制模式

    ESP_LOGI(TAG, "setChargeControlCur:%u", axp.getChargeControlCur());
    ESP_LOGI(TAG, "getCoreTemp:%.2f C", axp.getTemp());

    // Backup battery charge control
    // Backup Battery model: KTS CR2032W 3.0V 220mAh
    axp.setBackupChargeControl(AXP202_ON);
    axp.setBackupChargeVoltage(AXP202_BACKUP_VOLTAGE_3V0);
    axp.setBackupChargeCurrent(AXP202_BACKUP_CURRENT_100UA);

    axp.setGPIOMode(AXP_GPIO_0, AXP_IO_OUTPUT_HIGH_MODE); // 打开主板指示灯PIO0
    axp.gpioWrite(AXP_GPIO_0, 1);
}

static void axp_info()
{
    if (axp.isDCDC2Enable())
    {
        ESP_LOGI(TAG, "DC2: %u mV", axp.getDCDC2Voltage());
    }
    else
    {
        ESP_LOGI(TAG, "DC2: DISABLE");
    }

    if (axp.isDCDC3Enable())
    {
        ESP_LOGI(TAG, "DC3: %u mV", axp.getDCDC3Voltage());
    }
    else
    {
        ESP_LOGI(TAG, "DC3: DISABLE");
    }

    if (axp.isLDO2Enable())
    {
        ESP_LOGI(TAG, "LDO2: %u mV", axp.getLDO2Voltage());
    }
    else
    {
        ESP_LOGI(TAG, "LDO2: DISABLE");
    }

    if (axp.isLDO3Enable())
    {
        ESP_LOGI(TAG, "LDO3: %u mV", axp.getLDO3Voltage());
    }
    else
    {
        ESP_LOGI(TAG, "LDO3: DISABLE");
    }

    if (axp.isLDO4Enable())
    {
        ESP_LOGI(TAG, "LDO4: %u mV", axp.getLDO4Voltage());
    }
    else
    {
        ESP_LOGI(TAG, "LDO4: DISABLE");
    }

    if (axp.isExtenEnable())
    {
        ESP_LOGI(TAG, "Exten: ENABLE");
    }
    else
    {
        ESP_LOGI(TAG, "Exten: DISABLE");
    }
}

extern "C" void app_main(void)
{
    ESP_ERROR_CHECK(i2c_master_init());

    axp_init();

    axp_info();

    axp_irq_init();

    axp_config();

    // //! Enable all irq channel
    axp.enableIRQ(AXP202_ALL_IRQ, true);

    axp.clearIRQ();

    uint32_t io_num;
    for (;;) {

        if (xQueueReceive(gpio_evt_queue, &io_num, portMAX_DELAY)) {
            if (io_num == AXP_ISR_GPIO) {
                axp.readIRQ();
                if (axp.isPEKShortPressIRQ()) {
                    ESP_LOGI(TAG, "AXP202 PEK key Click");
                }
                axp.clearIRQ();
            }
        }
    }
}

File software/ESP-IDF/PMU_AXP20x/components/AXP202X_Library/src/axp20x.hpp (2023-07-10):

/////////////////////////////////////////////////////////////////
/*

           __   _______ ___   ___ ___
     /\    \ \ / /  __ \__ \ / _ \__ \
    /  \    \ V /| |__) | ) | | | | ) |
   / /\ \    > < |  ___/ / /| | | |/ /
  / ____ \  / . \| |    / /_| |_| / /_
 /_/    \_\/_/ \_\_|   |____|\___/____|



MIT License

Copyright (c) 2019 lewis he

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
axp20x.h - Arduino library for X-Power AXP202 chip.
Created by Lewis he on April 1, 2019.
github:https://github.com/lewisxhe/AXP202X_Libraries
*/
/////////////////////////////////////////////////////////////////
#pragma once

#ifdef __cplusplus
extern "C" {
#endif

#ifdef ARDUINO
#include <Arduino.h>
#include <Wire.h>
#else
#include <stdint.h>
#include <string.h>
#endif

// #define AXP_DEBUG_PORT  Serial
#ifdef AXP_DEBUG_PORT
#ifdef ARDUINO
#define AXP_DEBUG(fmt, ...)         AXP_DEBUG_PORT.printf_P((PGM_P)PSTR(fmt), ##__VA_ARGS__)
#else
#define AXP_DEBUG(...)              printf(__VA_ARGS__)
#endif

#else
#define AXP_DEBUG(...)
#endif

#ifndef RISING
#define RISING 0x01
#endif

#ifndef FALLING
#define FALLING 0x02
#endif

#ifdef _BV
#undef _BV
#endif
#define _BV(b)                                  (1ULL << (b))

//! Error Code
#define AXP_PASS                                (0)
#define AXP_FAIL                                (-1)
#define AXP_INVALID                             (-2)
#define AXP_NOT_INIT                            (-3)
#define AXP_NOT_SUPPORT                         (-4)
#define AXP_ARG_INVALID                         (-5)

//! Chip Address
#define AXP202_SLAVE_ADDRESS                    (0x34U)     //! 定制地址?(0x35U)
#define AXP192_SLAVE_ADDRESS                    (0x34U)
#define AXP173_SLAVE_ADDRESS                    (0x34U)

//! Chip ID
#define AXP202_CHIP_ID                          (0x41)
#define AXP192_CHIP_ID                          (0x03)
#define AXP173_CHIP_ID                          (0xAD)      //! Axp173 does not have  a chip ID, given a custom ID

//! Logic states
#define AXP202_ON                               (1)
#define AXP202_OFF                              (0)

//! REG MAP
#define AXP202_STATUS                           (0x00)
#define AXP202_MODE_CHGSTATUS                   (0x01)
#define AXP202_OTG_STATUS                       (0x02)
#define AXP202_IC_TYPE                          (0x03)
#define AXP202_DATA_BUFFER1                     (0x04)
#define AXP202_DATA_BUFFER2                     (0x05)
#define AXP202_DATA_BUFFER3                     (0x06)
#define AXP202_DATA_BUFFER4                     (0x07)
#define AXP202_DATA_BUFFER5                     (0x08)
#define AXP202_DATA_BUFFER6                     (0x09)
#define AXP202_DATA_BUFFER7                     (0x0A)
#define AXP202_DATA_BUFFER8                     (0x0B)
#define AXP202_DATA_BUFFER9                     (0x0C)
#define AXP202_DATA_BUFFERA                     (0x0D)
#define AXP202_DATA_BUFFERB                     (0x0E)
#define AXP202_DATA_BUFFERC                     (0x0F)
#define AXP202_LDO234_DC23_CTL                  (0x12)
#define AXP202_DC2OUT_VOL                       (0x23)
#define AXP202_LDO3_DC2_DVM                     (0x25)
#define AXP202_DC3OUT_VOL                       (0x27)
#define AXP202_LDO24OUT_VOL                     (0x28)
#define AXP202_LDO3OUT_VOL                      (0x29)
#define AXP202_IPS_SET                          (0x30)
#define AXP202_VOFF_SET                         (0x31)
#define AXP202_OFF_CTL                          (0x32)
#define AXP202_CHARGE1                          (0x33)
#define AXP202_CHARGE2                          (0x34)
#define AXP202_BACKUP_CHG                       (0x35)
#define AXP202_POK_SET                          (0x36)
#define AXP202_DCDC_FREQSET                     (0x37)
#define AXP202_VLTF_CHGSET                      (0x38)
#define AXP202_VHTF_CHGSET                      (0x39)
#define AXP202_APS_WARNING1                     (0x3A)
#define AXP202_APS_WARNING2                     (0x3B)
#define AXP202_TLTF_DISCHGSET                   (0x3C)
#define AXP202_THTF_DISCHGSET                   (0x3D)
#define AXP202_DCDC_MODESET                     (0x80)
#define AXP202_ADC_EN1                          (0x82)
#define AXP202_ADC_EN2                          (0x83)
#define AXP202_ADC_SPEED                        (0x84)
#define AXP202_ADC_INPUTRANGE                   (0x85)
#define AXP202_ADC_IRQ_RETFSET                  (0x86)
#define AXP202_ADC_IRQ_FETFSET                  (0x87)
#define AXP202_TIMER_CTL                        (0x8A)
#define AXP202_VBUS_DET_SRP                     (0x8B)
#define AXP202_HOTOVER_CTL                      (0x8F)
#define AXP202_GPIO0_CTL                        (0x90)
#define AXP202_GPIO0_VOL                        (0x91)
#define AXP202_GPIO1_CTL                        (0x92)
#define AXP202_GPIO2_CTL                        (0x93)
#define AXP202_GPIO012_SIGNAL                   (0x94)
#define AXP202_GPIO3_CTL                        (0x95)
#define AXP202_INTEN1                           (0x40)
#define AXP202_INTEN2                           (0x41)
#define AXP202_INTEN3                           (0x42)
#define AXP202_INTEN4                           (0x43)
#define AXP202_INTEN5                           (0x44)
#define AXP202_INTSTS1                          (0x48)
#define AXP202_INTSTS2                          (0x49)
#define AXP202_INTSTS3                          (0x4A)
#define AXP202_INTSTS4                          (0x4B)
#define AXP202_INTSTS5                          (0x4C)

//Irq control register
#define AXP192_INTEN1                           (0x40)
#define AXP192_INTEN2                           (0x41)
#define AXP192_INTEN3                           (0x42)
#define AXP192_INTEN4                           (0x43)
#define AXP192_INTEN5                           (0x4A)
//Irq status register
#define AXP192_INTSTS1                          (0x44)
#define AXP192_INTSTS2                          (0x45)
#define AXP192_INTSTS3                          (0x46)
#define AXP192_INTSTS4                          (0x47)
#define AXP192_INTSTS5                          (0x4D)

#define AXP192_DC1_VLOTAGE                      (0x26)
#define AXP192_LDO23OUT_VOL                     (0x28)
#define AXP192_GPIO0_CTL                        (0x90)
#define AXP192_GPIO0_VOL                        (0x91)
#define AXP192_GPIO1_CTL                        (0X92)
#define AXP192_GPIO2_CTL                        (0x93)
#define AXP192_GPIO012_SIGNAL                   (0x94)
#define AXP192_GPIO34_CTL                       (0x95)
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

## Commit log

2023-07-06 update md
    [BOM_邮票孔模块2023-07-04.xlsx]
2023-07-10 update bom
    [BOM_邮票孔模块2023-07-04.xlsx, BOM_邮票孔模块2023-07-11.xlsx]
